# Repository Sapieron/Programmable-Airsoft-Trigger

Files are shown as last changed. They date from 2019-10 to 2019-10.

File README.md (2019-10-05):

# Programmable Airsoft Trigger - an STM32F030C8T6 based project
## Short Brief
Programmable Airsoft Trigger - designed to replace traditional electromechanical switch present in airsoft replica to control gearbox opeartion.
## Project's status:
**In development**
### List of things left to do:
* Implement fire selector switch ,,on fly" programming, to let user decide burst cycles, semi only etc.
* An OLED I2C display to show the player how many shots were shot
* Minor hardware update
## The Problem
As the usual circuitry closes and lets the current flow, just a moment before contacts meet each other a spark is present between these contacts.
After a longer usage it leads to oxydation of metal and creating a layer of carbon, which leads to higher resistance, therefore heat is generated and switch gets damaged.
Here's some quick maths:

For an `11,1V` LiPo battery with `20C/40C` at burst and at `t=0` a DC motor acts as a short circuit, thus resulting in a full current burst from the battery, 
which is roughly **30A** at `t=0`. Following this thinking, let's say the resistance of a damaged trigger switch is 1 Ohm - that's not really that much, huh?

Power dissipated on contacts may be calulated with a simple equation: `R * I^2` . As the current is squared, it's easily seen how dramatically power raises to 900W ! If it would work for a couple of seconds, the airsoft replica would be like a portable microwave :)
## The Solution
A transistor has been used as a switch ever since it has been developed. If we consider large currents like in this application, a field transistor suits our needs.
A P-channel MOSFET transistor STL42P6LLF6 has it's drain-source resistance at typically 0,023 Ohm, so for a moment maximal power dissipated on a junction is less then 21W.
## Technologies used
For this project following technologies, programs and hardware were used:
* C (embedded C11)
* Altium Designer 18.1.7
* Eclipse IDE with GCC compiler
* ST-Link V2.1 programmer/debugger
* STM32F030C8T6 ARM architecture based microcontroller
* Custom hardware
## Setup
### Software Setup
This project was designed to be out-ouf-package ready to work with, no software setup is needed.
### Memory Flashing
Use SWD connector presented onboard to flash the board with an external ST-Link programmer. Pinouts are available in this repository. Next, connect your hardware programmer and flash the `.elf` file (how to do that depends on IDE or software flashing software used - please refer to tutarials specific to your setup)
## Inspiration
As an airsoft player I found it frustrating to fight with my own setup in a longer game as my battery would eventually die after a couple of magazines shot. Also, trigger response wasn't acceptable.
Inspired by airsoft forums I decided to use an N-MOSFET as a switch. Results were fascinating, as my battery life doubled, and trigger felt gentle as a feather.
Later I found out that there were commercial programable triggers that had fancy funcionality like 3-shot bursts, low battery warnings etc.
I bought one eventually, but I couldn't see why these cost about 100 euros (there are even 180 euros price tag ones). Then I got an idea - why can't I make one by myself?
After a couple of years I learned more and more about hardware design, started studying at technical university and got into C coding. It was about that time I decided to give that project a try.
Books I always find usefull:
* Tomasz Francuz ,,C language for AVR microcontrollers"
* Robert C. Martin ,,Clean Code"
* James Grenning ,,Test-Driven Development for Embedded C"
## Contact
Created by Paweł Klisz @ pawelochojec@gmail.com- feel free to contact me!

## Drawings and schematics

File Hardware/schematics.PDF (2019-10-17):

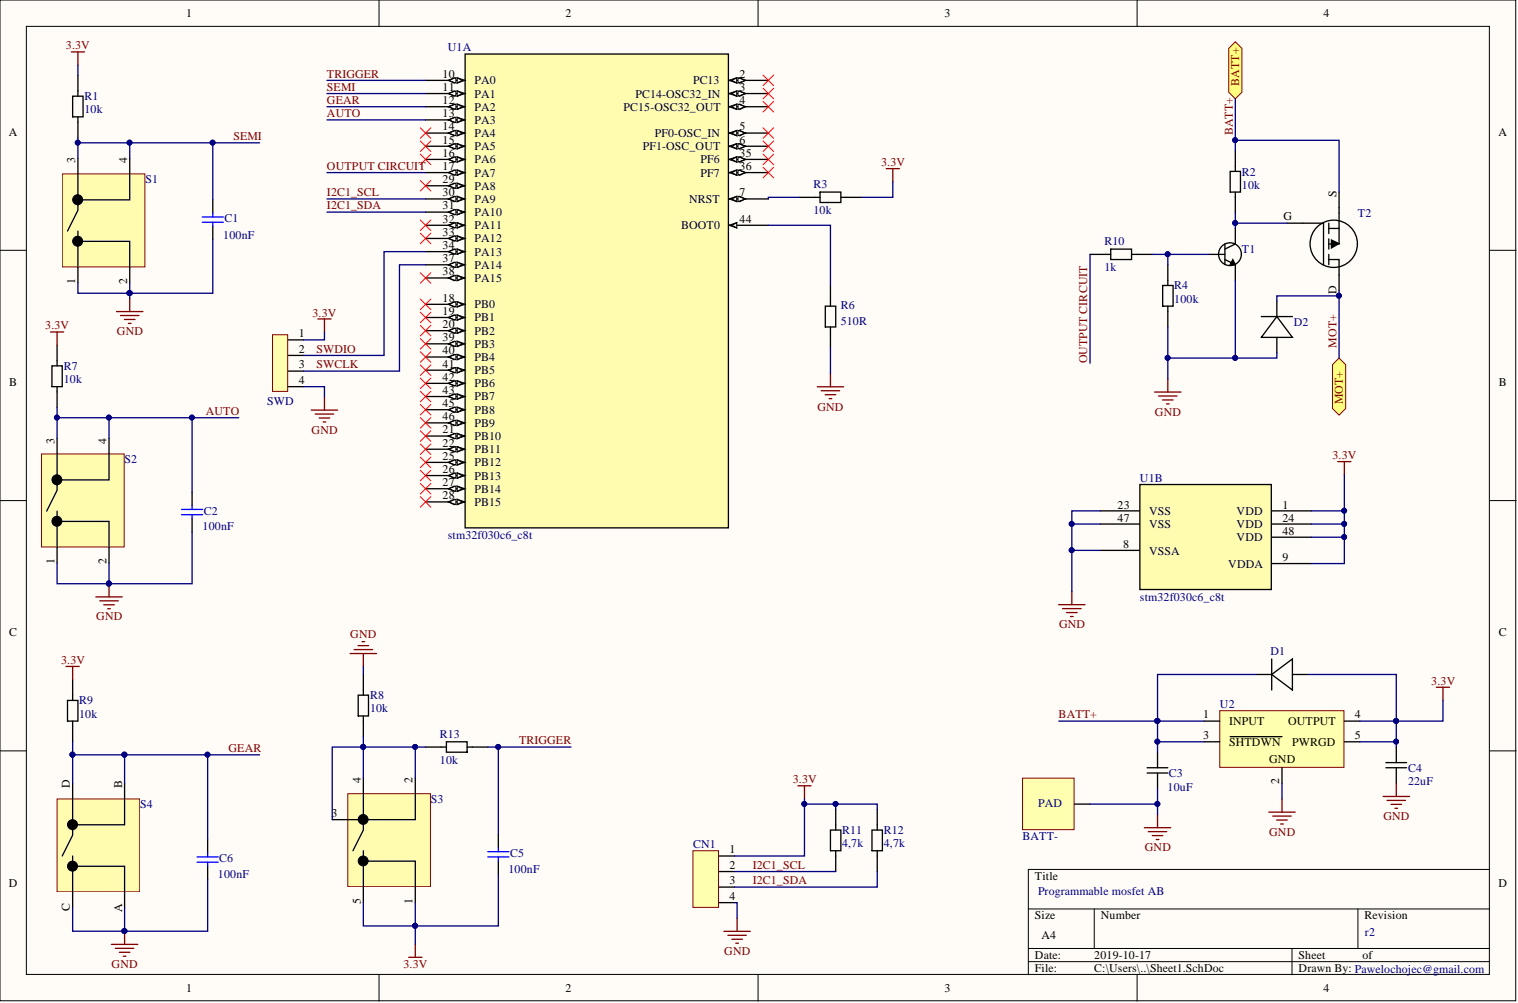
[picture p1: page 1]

3.3 V DIO | 3 8

4 7 | 2 4
8 | 4 8

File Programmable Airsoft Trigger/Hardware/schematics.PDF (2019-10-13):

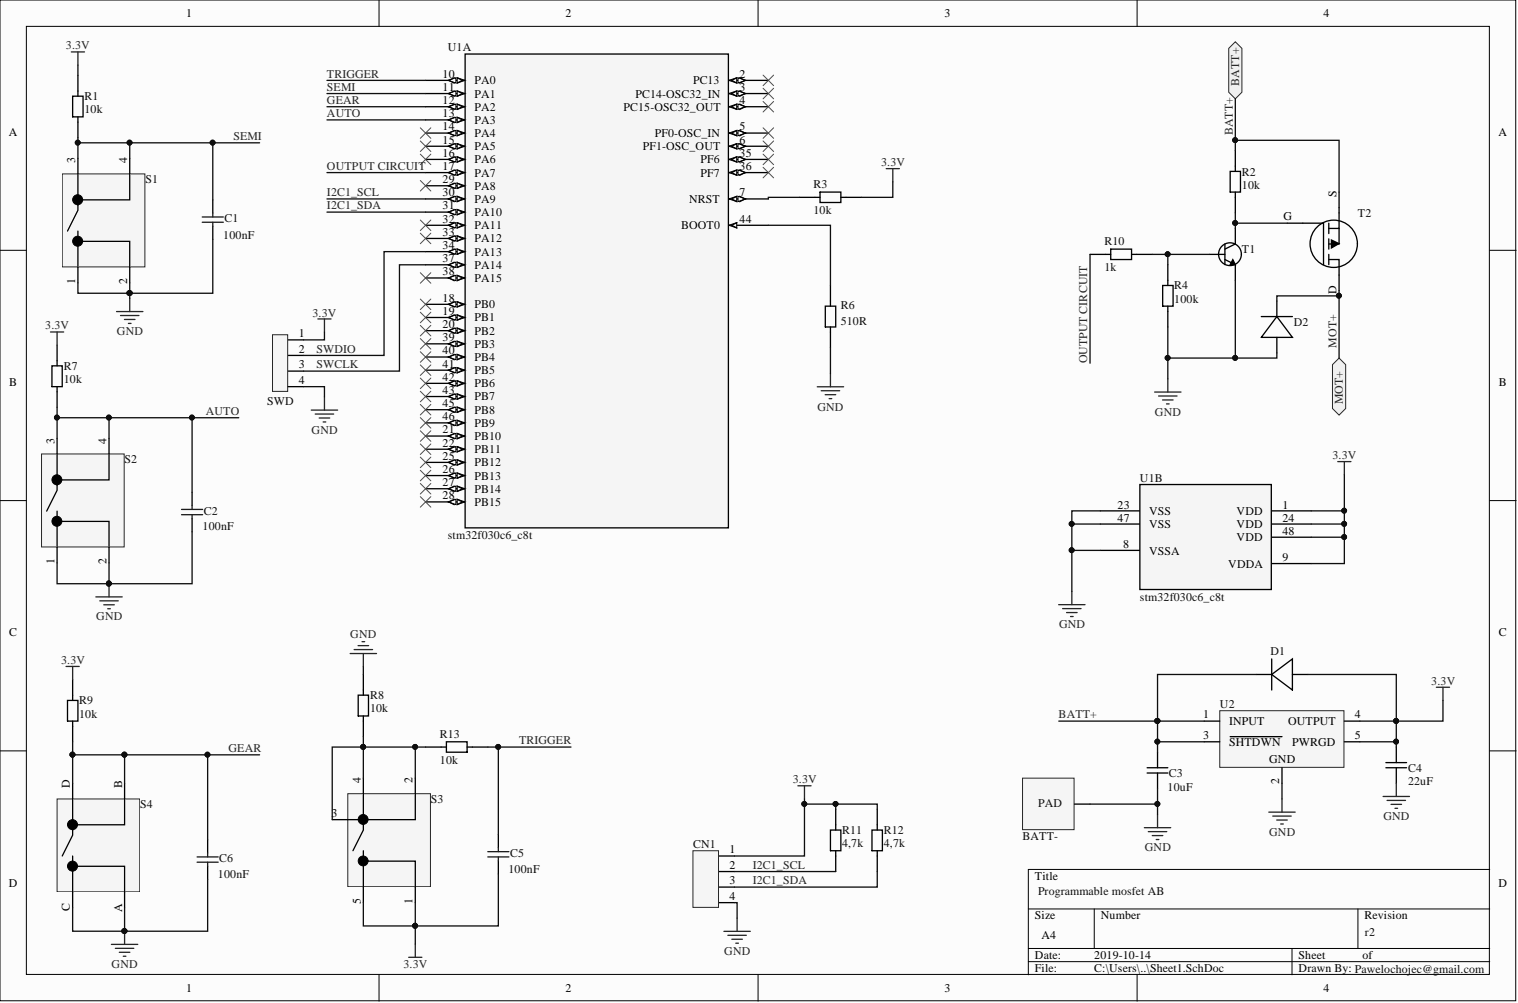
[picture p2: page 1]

3.3 V DIO | 3 8

4 7 | 2 4
8 | 4 8

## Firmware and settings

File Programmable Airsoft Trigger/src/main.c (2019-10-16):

/* ******************************************
    Programmable Trigger for airsoft replicas
    Copyright (c) 2019 Pawel Klisz (pawelochojec@gmail.com)
    [Released under MIT License. Please refer to license.txt for details]
   ****************************************** */

#include <PASGM_Lib.h>
#include <stdint.h>
#include <string.h>
#include <STM32F030C8T6.h>
#include <STM32F030C8T6_gpio.h>
#include <STM32F030C8T6_rcc.h>
#include <STM32F030C8T6_irq.h>
#include <STM32F030C8T6_timer.h>
#include <STM32F030C8T6_systick.h>
#include <STM32F030C8T6_pwr.h>


#define MOTOR_PWM_FREQUENCY_IN_HZ 				1000
#define MOTOR_PWM_DUTY_CYCLE_IN_PERCENT			2


void Setup();

GPIO_Handle_t autoHandler_t,
semiHandler_t,
triggerHandler_t,
gearSensorHandler_t,
motorHandler_t;

TIMER3_Handler_t motorBeeping;

SysTick_Handler_t sysTickHandler;

PASGM_BeepMotorHandler_t BeepMotorHandler;

int main(void){
	if(! PWR_isFlagSet(PWR_CSR_SBF)){	//check if device wakes up from standby mode
		Setup();
		if( GPIO_IsPinPressed(&semiHandler_t) || GPIO_IsPinPressed(&autoHandler_t) || GPIO_IsPinPressed(&triggerHandler_t)){
			GPIO_DeInit(&semiHandler_t);
			GPIO_DeInit(&autoHandler_t);
			GPIO_DeInit(&triggerHandler_t);
			GPIO_DeInit(&motorHandler_t);
			//TODO reset system with systemControlBlock registers
		}

		NVIC_InitVector(NVIC_IRQNUMBER_TIMER3);
		TIMER3_Init(&motorBeeping);

		BeepMotorHandler.beepForTimes = 2;
		BeepMotorHandler.intervalOfBeepsInMs = 200;
		BeepMotorHandler.durationOfBeepInMs = 400;
		PASGM_BeepMotorHandling(&BeepMotorHandler, &sysTickHandler, &motorBeeping);

		Systick_EnableTimerForSetTimeInMs(&sysTickHandler,2000, DISABLE);

		while( ! SysTick_isFlagSet(&sysTickHandler))
			if(GPIO_IsPinPressed(&semiHandler_t)){
				sysTickHandler.config.counterInitialize = DISABLE;
				SysTick_CounterHandling(&sysTickHandler);

				PASGM_StartUserProgrammingProcedure();

				GPIO_DeInit(&semiHandler_t);
				GPIO_DeInit(&autoHandler_t);
				GPIO_DeInit(&triggerHandler_t);
				GPIO_DeInit(&motorHandler_t);
				//TODO reset system with systemControlBlock registers
			}

		sysTickHandler.config.counterInitialize = DISABLE;
		SysTick_CounterHandling(&sysTickHandler);

		BeepMotorHandler.beepForTimes = 4;
		BeepMotorHandler.intervalOfBeepsInMs = 300;
		BeepMotorHandler.durationOfBeepInMs = 200;
		PASGM_BeepMotorHandling(&BeepMotorHandler, &sysTickHandler, &motorBeeping);

		TIMER3_DeInit(&motorBeeping);

		motorHandler_t.PinConfig.PinMode = GPIO_MODE_OUTPUT;
		motorHandler_t.PinConfig.alternateFunMode = DISABLE;
		motorHandler_t.PinConfig.PUPD = GPIO_PUPDR_PULLDOWN;
		GPIO_Init(&motorHandler_t);

		GPIO_ExtiInit(GPIO_EXTI_FallingTrigSR, &triggerHandler_t);	//TODO: that should be handled as event,
		//as no interrupt handling is done by compiler, thus procedure is done faster
		PWR_LowPowerHandling();
		PWR_WKUPxHandling(PWR_CSR_EWUP1, ENABLE);
	}else{
		//TODO make it SetupAfterWakeup
		GPIO_Init(&semiHandler_t);
		GPIO_Init(&autoHandler_t);

		RCC_SetAPBClockPrescaler(RCC_CFGR_PRESCALER_APB_div8);
		RCC_SetAHBClockPrescaler(RCC_CFGR_PRESCALER_AHB_div16);

		EXTI_InitEvent(triggerHandler_t.PinConfig.PinNumber);
		EXTI_SWIER_Handling(ENABLE,triggerHandler_t.PinConfig.PinNumber);
	}
	while(1);
}


void Setup(){
	//TODO whole setup should be saved in flash
	memset(&motorHandler_t, CLEAR, sizeof(motorHandler_t));
	memset(&motorBeeping, CLEAR, sizeof(motorBeeping));
	memset(&autoHandler_t, CLEAR, sizeof(autoHandler_t));
	memset(&sysTickHandler, CLEAR, sizeof sysTickHandler);

	motorHandler_t.pGPIOx = GPIOA_p;
	motorHandler_t.PinConfig.PinNumber = GPIO_PIN_NUMBER_7;
	motorHandler_t.PinConfig.PinMode = GPIO_MODE_AF;
	motorHandler_t.PinConfig.alternateFunMode = GPIO_ALTERNATE_FUN_MODE_AF1;
	motorHandler_t.PinConfig.PUPD = GPIO_PUPDR_NOPUPD;

	semiHandler_t.pGPIOx = GPIOA_p;
	semiHandler_t.PinConfig.PinNumber = GPIO_PIN_NUMBER_1;
	semiHandler_t.PinConfig.PinMode = GPIO_MODE_INPUT;
	semiHandler_t.PinConfig.PUPD = GPIO_PUPDR_PULLUP;

	autoHandler_t.pGPIOx = GPIOA_p;
	autoHandler_t.PinConfig.PinNumber = GPIO_PIN_NUMBER_3;
	autoHandler_t.PinConfig.PinMode = GPIO_MODE_INPUT;
	autoHandler_t.PinConfig.PUPD = GPIO_PUPDR_PULLUP;


	//this structure is valid only till WKUP1 is initialized, then it's overwritten
	triggerHandler_t.pGPIOx = GPIOA_p;
	triggerHandler_t.PinConfig.PinNumber = GPIO_PIN_NUMBER_0;
	triggerHandler_t.PinConfig.PinMode = GPIO_MODE_INPUT;
	triggerHandler_t.PinConfig.PUPD = GPIO_PUPDR_PULLDOWN;

	gearSensorHandler_t.pGPIOx = GPIOA_p;
	gearSensorHandler_t.PinConfig.PinNumber = GPIO_PIN_NUMBER_2;
	gearSensorHandler_t.PinConfig.PinMode = GPIO_MODE_INPUT;
	gearSensorHandler_t.PinConfig.PUPD = GPIO_PUPDR_PULLUP;

	sysTickHandler.pSysTick = SYSTICK_p;
	sysTickHandler.config.clockSource = SYSTICK_CSR_CLKSOURCE_PROC_CLK;
	sysTickHandler.config.exceptionRequestEnable = DISABLE;
	sysTickHandler.config.counterInitialize = DISABLE;


	RCC_SetAPBClockPrescaler(RCC_CFGR_PRESCALER_APB_div8);
	RCC_SetAHBClockPrescaler(RCC_CFGR_PRESCALER_AHB_div16);


	motorBeeping.pTIMER3 = TIMER3_p;
	motorBeeping.TIMER3Config.PWMConfig.frequencyInHz = MOTOR_PWM_FREQUENCY_IN_HZ;
	motorBeeping.TIMER3Config.PWMConfig.dutyCycleInPercent = MOTOR_PWM_DUTY_CYCLE_IN_PERCENT;
	motorBeeping.TIMER3Config.PWMConfig.channel = TIMER_PWM_CONFIG_CHANNEL_2;
	motorBeeping.TIMER3Config.PWMConfig.PWMMode = TIMER_PWM_CONFIG_MODE_PWM1;
	motorBeeping.TIMER3Config.PWMConfig.ActivePolarity = TIMER_PWM_CONFIG_ACTIVE_POLARITY_HIGH;
	motorBeeping.TIMER3Config.PWMConfig.enablePWMMode = ENABLE;
	motorBeeping.TIMER3Config.counterInitialize = DISABLE;


	GPIO_Init(&motorHandler_t);
	GPIO_Init(&semiHandler_t);
	GPIO_Init(&autoHandler_t);
	GPIO_Init(&triggerHandler_t);
}

void EXTI0_1_IRQHandler(){
	GPIO_IrqPendingRegisterHandling(&triggerHandler_t);
	GPIO_ToggleOutputPin(&motorHandler_t);
}

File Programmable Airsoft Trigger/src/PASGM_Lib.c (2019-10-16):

/*
 * PASGM_Lib.c
 *
 *  Created on: Oct 6, 2019
 *      Author: pawel
 */

#include <PASGM_Lib.h>

/******************************************************************************************
 ********************** Private functions *************************************************
 ******************************************************************************************/



/******************************************************************************************
 ********************** Main functions definitions ****************************************
 ******************************************************************************************/

void PASGM_StartUserProgrammingProcedure(){
	//TODO Write this procedure
	//TODO use flash memory to store last remembered configuration
}

void PASGM_BeepMotorHandling(PASGM_BeepMotorHandler_t *BeepMotorHandler, SysTick_Handler_t *sysTickHandler, TIMER3_Handler_t *motorBeeping){
	sysTickHandler->config.counterInitialize = DISABLE;
	SysTick_CounterHandling(sysTickHandler);

	sysTickHandler->config.autoReloadValue = TIME_BASE_OF_ONE_MS_FOR_SYSTICK * (BeepMotorHandler->durationOfBeepInMs + BeepMotorHandler->durationOfBeepInMs);
	sysTickHandler->config.counterValue = 0;
	SysTick_Init(sysTickHandler);

	sysTickHandler->config.counterInitialize = ENABLE;
	SysTick_CounterHandling(sysTickHandler);

	for(uint16_t i = 0; i < BeepMotorHandler->beepForTimes ; ++i){
		motorBeeping->TIMER3Config.counterInitialize = ENABLE;
		TIMER3_CounterHandling(motorBeeping);

		while( (sysTickHandler->config.autoReloadValue - (TIME_BASE_OF_ONE_MS_FOR_SYSTICK * BeepMotorHandler->durationOfBeepInMs) ) <= SysTick_ReadCurrentCounterValue(sysTickHandler) );

		motorBeeping->TIMER3Config.counterInitialize = DISABLE;
		TIMER3_CounterHandling(motorBeeping);

		while( ! SysTick_isFlagSet(sysTickHandler) );
	}
	sysTickHandler->config.counterInitialize = DISABLE;
	SysTick_CounterHandling(sysTickHandler);
}

/******************************************************************************************
 ********************** Private functions *************************************************
 ******************************************************************************************/

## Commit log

2019-08-22 upgraded some libraries
    [Programowalny mosfet ASG Debug generic.cfg, Programowalny mosfet ASG Debug.cfg]
2019-10-05 Renamed project name, comitted new libraries
    [Programowalny mosfet ASG Debug generic.cfg, Programowalny mosfet ASG Debug.cfg]
2019-10-12 added System Control Block functions for power management
2019-10-13 Added complete hardware designs
    [Sheet1.SchDoc, mosfet_STM32.PcbDoc, mosfet_STM32.PcbLib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]
2019-10-13 Added hardware schematics and production files
    [Sheet1.SchDoc, mosfet_STM32.PcbDoc, mosfet_STM32.PcbLib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]
2019-10-13 moved Hardware/ folder
    [Sheet1.SchDoc, mosfet_STM32.PcbDoc, mosfet_STM32.PcbLib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]
2019-10-17 updated trigger switch layout, as it was badly positioned
    [mosfet_STM32.PcbDoc, mosfet_STM32.PcbLib]
